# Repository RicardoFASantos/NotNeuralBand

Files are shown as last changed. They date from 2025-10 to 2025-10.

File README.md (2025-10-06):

## 🎥 Vintage Video gallery

### General Pre-trained gestures based on muscle and motion signals
Assembly Tutorial (https://www.youtube.com/watch?v=8NtrBwCGjhw)

### Assembly of a 3D printed bracelet with a PCB board and sensors
Assembly Tutorial (https://www.youtube.com/watch?v=L2T6ioK4wVY)

---

## ✨ Features

- **Analog Front-End:** TI ADS1294 – 4-channel, 24-bit ADC with integrated EMG front-end  
- **MCU:** ATmega1284P – 8-bit AVR, 128KB Flash, 16KB SRAM  
- **Motion Sensing:** NXP MMA8652 3-axis accelerometer  
- **Wireless:** BR-LE4.0-D2A Bluetooth Low Energy module  
- **LED Driver:** IS31FL3199 with RGB LED indicators  
- **Power Management:**
  - MCP73831 Li-Ion/Li-Po charger  
  - TPS78233 LDO regulator  
  - NCP300L voltage detector  

- **Connectivity:**
  - Micro-USB charging & power  
  - 2x pin headers for expansion/debugging  
  - UART/SPI/I²C exposed  

---

## 🔧 Hardware Overview

- **PCB Material:** FR4, 1.6mm, 0.35µm Cu  
- **Board Layers:** 2-layer design  
- **Main Blocks:**
  - Power supply & battery charging  
  - Biosignal AFE (EMG)  
  - Microcontroller control  
  - Bluetooth module  
  - LED indicators  

---

## 🛠️ Manufacturing

To order PCBs:

1. Use the **Gerber files** in `/hardware`.  
2. Upload to a PCB manufacturer (e.g., JLCPCB, PCBWay, OSH Park).  
3. Provide BOM to source components.  
4. Assemble manually or via pick-and-place.

---

## ⚠️ Design Notes

- This design uses a **virtual ground electrode** implementation.  
  No physical ground electrode is required for operation, as the ADS1294 reference (RLD) is internally stabilized.  
  This simplifies assembly and makes the device more wearable.  

---

## 🚀 Getting Started

1. **Assemble the board** following the BOM.  
2. **Program the ATmega1284P** using ISP or bootloader (Arduino-compatible toolchains supported).  
3. **Power via Li-Ion battery or micro-USB**.  
4. **Connect via Bluetooth** to stream biosignals.  

---

## 📜 License

This project is released under the **CERN Open Hardware License v2**.  
You are free to **study, modify, produce, and distribute** this hardware, provided modifications and derivatives remain open.  

See [LICENSE](LICENSE) for details.

---

## 🤝 Contributing

Pull requests are welcome!  
You can help with:
- Firmware development examples  
- Better assembly guides  
- Testing & validation reports  
- Migrating schematics into KiCad for wider community use  

---

## 📧 Contact

Developed originally by **Ricardo Santos** with his friends from college Andreia Dias, Dora Inácio, Eduardo e Rui Santos.
For questions, suggestions, or collaborations:  
- Email: ricardo.santos.eb@gmail.com 
- LinkedIn: [ricardofasantos](https://www.linkedin.com/in/ricardofasantos/)  
- Twitter/X: [@RicardoSan43564](https://twitter.com/RicardoSan43564)
Open-sourced by the community for further research and prototyping.

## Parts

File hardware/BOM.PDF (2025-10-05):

## BOM -Minerva

Designator | Comment | Description | Footprint | Quantity | Value
BT1 | BR-LE4.0-D2A | BR-LE4.0-D2A | WML-C29A | 1
C1, C5, C7, C11, C14, C18, C27, C31 | C0402 | Capacitor | C0402 | 8 | 1nF
C2, C6, C8, C12, C15, C19, C28, C32, C33, C34, C36, C37, C40, C41 | C0402 | Capacitor | C0402 | 14 | 100nF
C3, C9, C16, C21, C24, C26, C29, C35, C38, C39, C42, C44, C46, C48 | C0402 | Capacitor | C0402 | 14 | 1uF
C4, C10, C17, C25, C30, C43, C45 | C0402 | Capacitor | C0402 | 7 | 0.1uF
C13, C23 | C0402 | Capacitor | C0402 | 2 | 0.01uF
C20 | C0603 | Capacitor | C0402 | 1 | 22uF
C22 | C0603 | Capacitor | C0402 | 1 | 10uF
C47, C49 | C0603 | Capacitor | C0603 | 2 | 4.7uF
D1 | LED2 | Typical RED, GREEN, YELLOW, AMBER GaAs LED | 3.2X1.6X1.1 | 1
FID1, FID2, FID3 | FD | Fiducial 1.5mm | Fiducial | 3
IC1 | MCP6041T-E/OT | MCP6041T-E/OT | SOT23-5 | 1
JP1 | 2x3 pinos | Pinos Macho Duplos 2.54mm | IDC-6 | 1
L1 | 5R | | 1206R | 1
P1 | WN09DH | | WN06DH | 1
P2 | 1551629-2 | Micro USB Splashproof | microUSB | 1
P3 | Header 2 | Header, 2-Pin | HDR1X2 | 1
Q2 | TP0101K | MOSFET P-channel 20V, 0.58A, SOT23 | SOT-23 | 1
R1, R23, R25, R26, R27, R30, R31, R32, R33, R40, R41, R42, R43 | R0402 | Resistor | R0402 | 13 | 10k
R2, R3, R4, R5, R6, R7, R8, R9, R11, R12, R13, R14, R18, R19, R20, R21 | R0402 | Resistor | R0402 | 16 | 348k
R10, R16, R17 | R0402 | Resistor | R0402 | 3 | 392k
R15, R22, R24, R38 | R0402 | Resistor | R0402 | 4 | 0
R28, R29 | R0402 | Resistor | R0402 | 2 | 300K
R34 | R0402 | Resistor | R0402 | 1 | 470
R35, R37, R44 | R0402 | Resistor | R0402 | 3 | 100k
R36, R45, R46, R47, R48, R49, R50, R51 | R0402 | Resistor | R0402 | 8 | 1M
R39 | R0402 | Resistor | R0402 | 1 | 330k
RGB1, RGB2, RGB3, RGB4, RGB5, RGB6 | RGB | LX0404SIUPGUSB | LX0404SIUPGUSB | 6
SW1 | | | Push Button | 1
U1 | ADS1294IPAG | 4-Channel, 24-Bit ADC with Integrated ECG Front End, -40 to 85 degC, 64-pin QFP (PAG64), Green (RoHS & no Sb/Br) | TI-PAG64_N | 1
U2 | ATmega1284P-MUR | 8-bit AVR Microcontroller, 128KB Flash, 4KB EEPROM, 16KB SRAM, 44-pin VQFN, Industrial Grade (-40°C to 85°C), Reel | 44M1_N | 1
U3 | MMA8652FCR1 | Accelerometer 3-Axis, 2g/4g/8g, 12 bit, DFN-10 (MMA8652FCR1) | MMA8652FC | 1
U4 | IS31FL3199 | | VQFN-20 (3x3mm) | 1
U5 | TPS78233 | Voltage regulator LDO, 150mA, IQ 0,5uA, SOT23-5 (TPS78233DDC) | SOT23-5 | 1

U6 | MCP73831T-2ACI/OT | Miniature Single-Cell, Fully Integrated Li-Ion, Li-Polymer Charge Management Controller, 4.2V, 5-Pin SOT-23, Industrial Temperature, Tape and Reel | SOT23-5 | 1
U7 | NCP300L | Voltage detector 3.4V, SOT23-5 NCP300L | SOT23-5 | 1
Y1 | Resonator | AVX | Resonator | 1

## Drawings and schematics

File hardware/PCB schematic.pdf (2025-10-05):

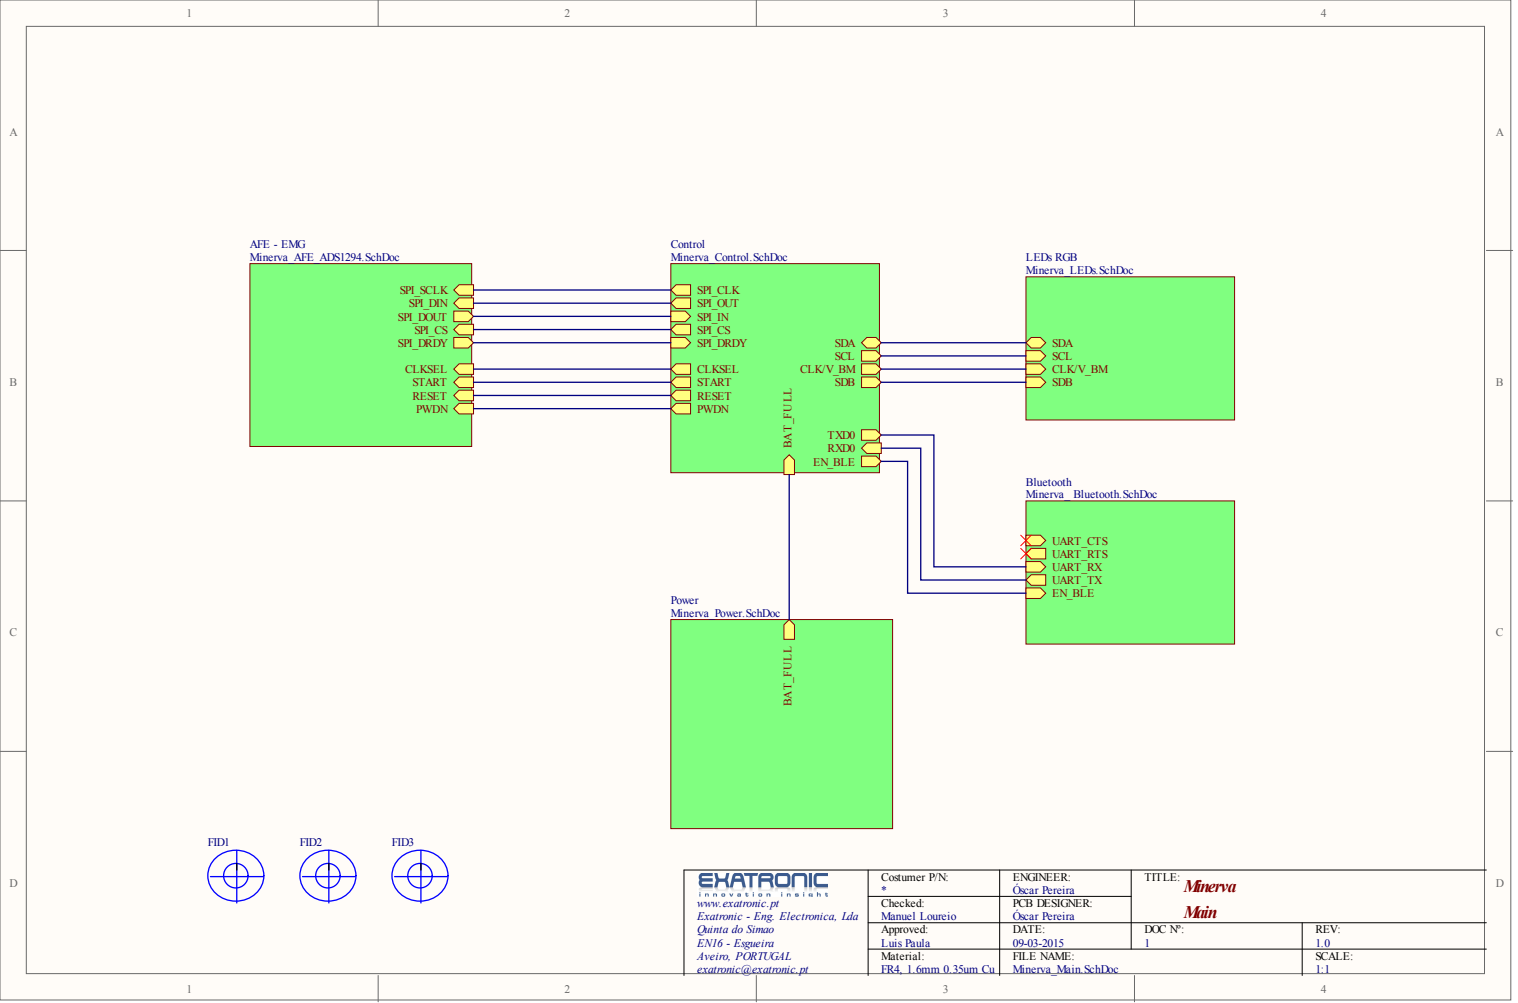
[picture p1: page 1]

www.exatronic.pt
Exatronic - Eng. Electronica, Lda
Quinta do Simao
EN16 - Esgueira
Aveiro, PORTUGAL
exatronic@exatronic.pt

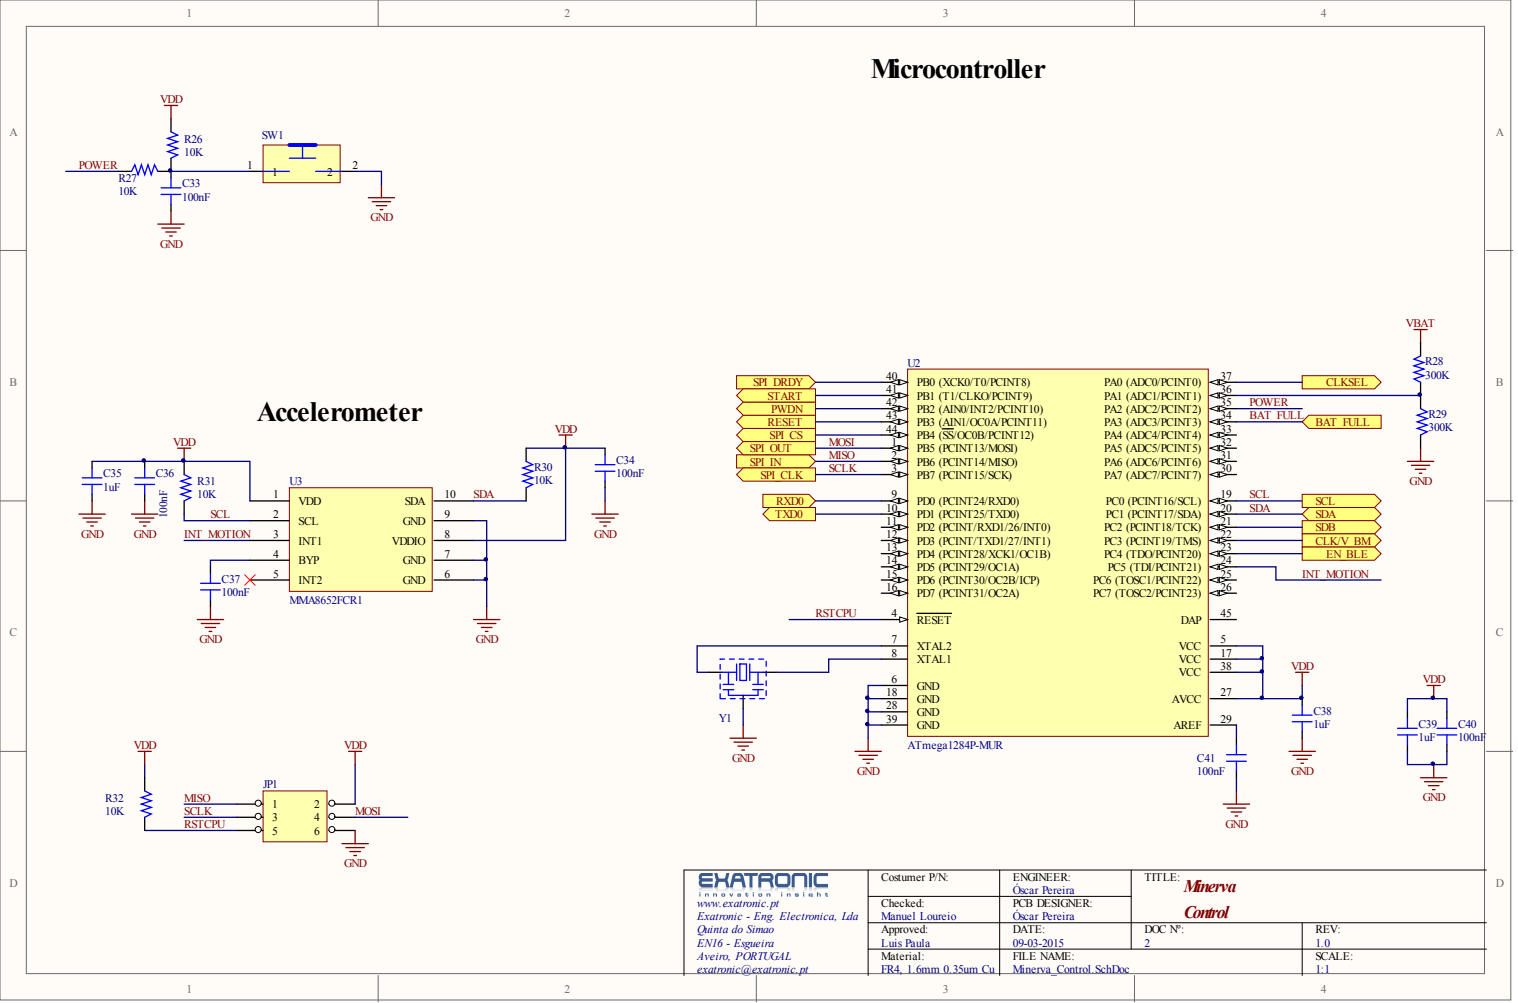
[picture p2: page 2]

XTAL1 8

GND 18

GND 39

www.exatronic.pt
Exatronic - Eng. Electronica, Lda

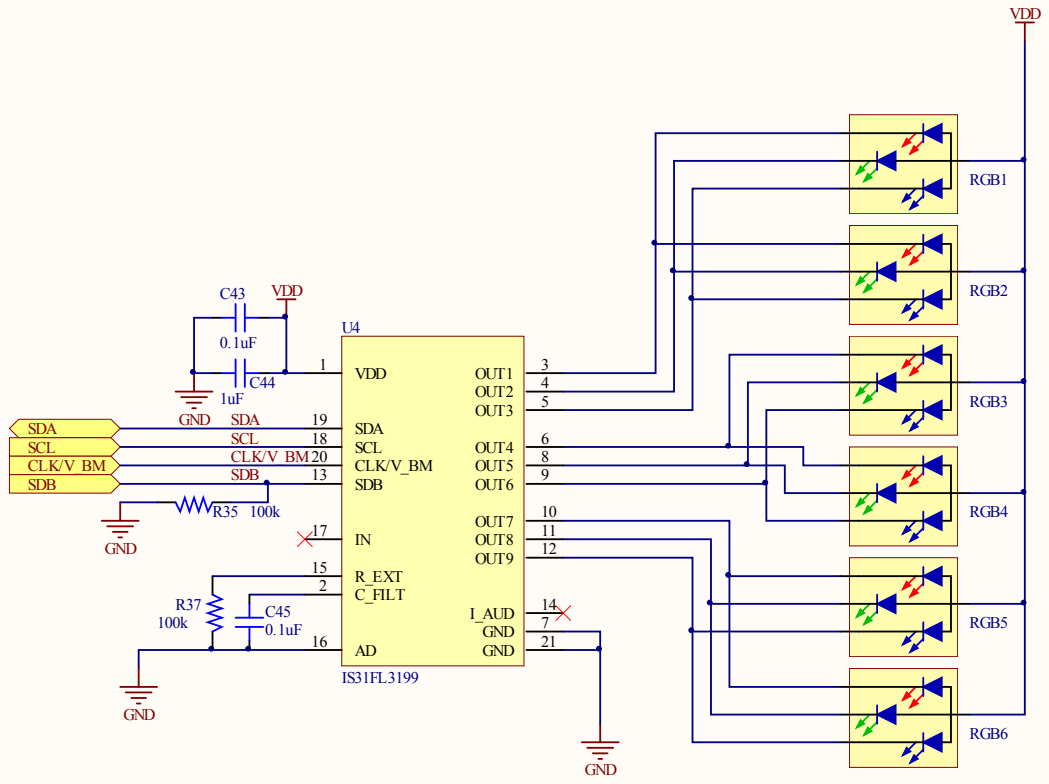
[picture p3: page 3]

1 0
1 1
1 2

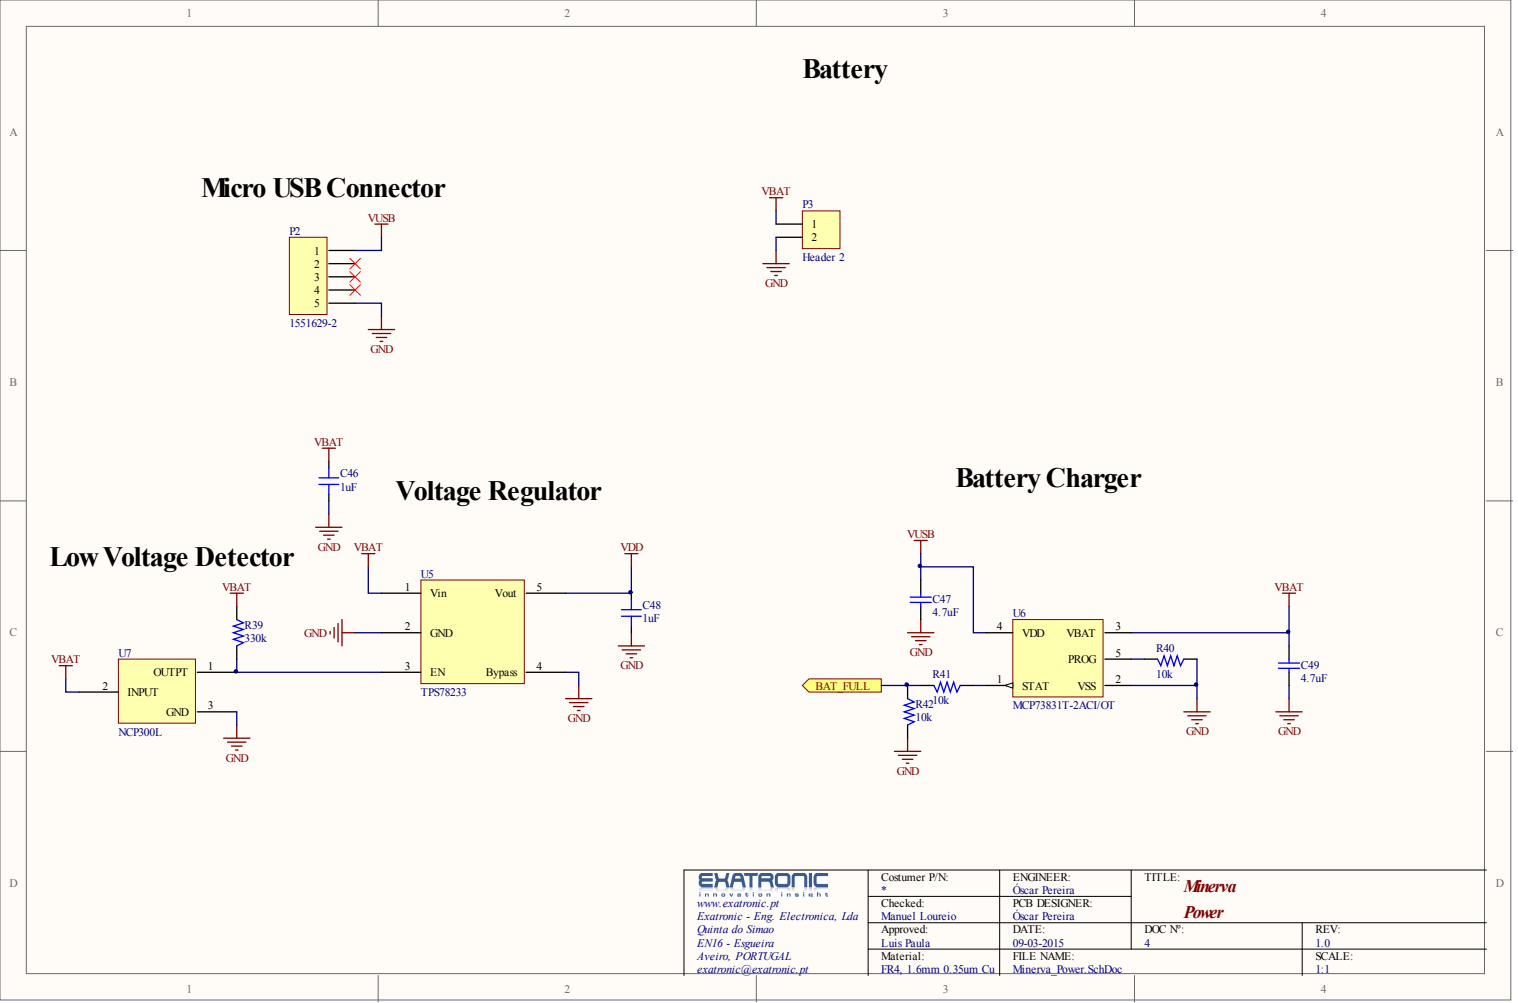
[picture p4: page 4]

Micro USB Connector VUSB

Battery Charger Voltage Regulator

www.exatronic.pt
Exatronic - Eng. Electronica, Lda

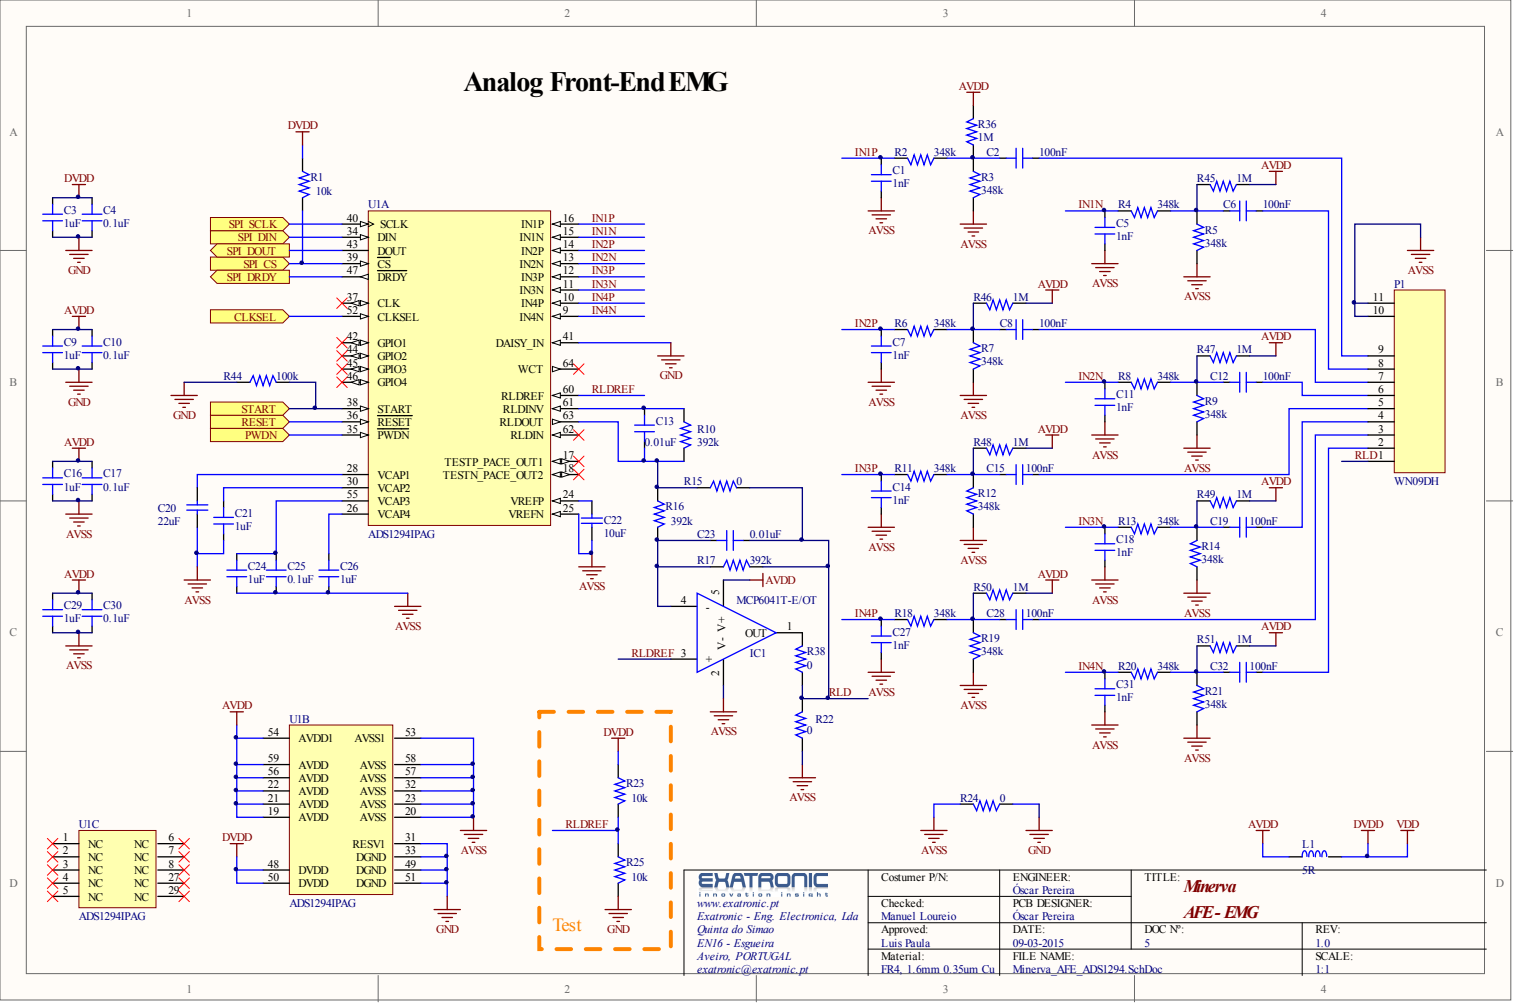
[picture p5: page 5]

4 3 | 1 4 IN2 P AVS R4
3 9 | 1 3 IN2 N

R4 7 1 M | AVDD

5 9 | 5 8
5 6 | 5 7
2 2 | 3 2
2 1 | 2 3
1 9 | 2 0

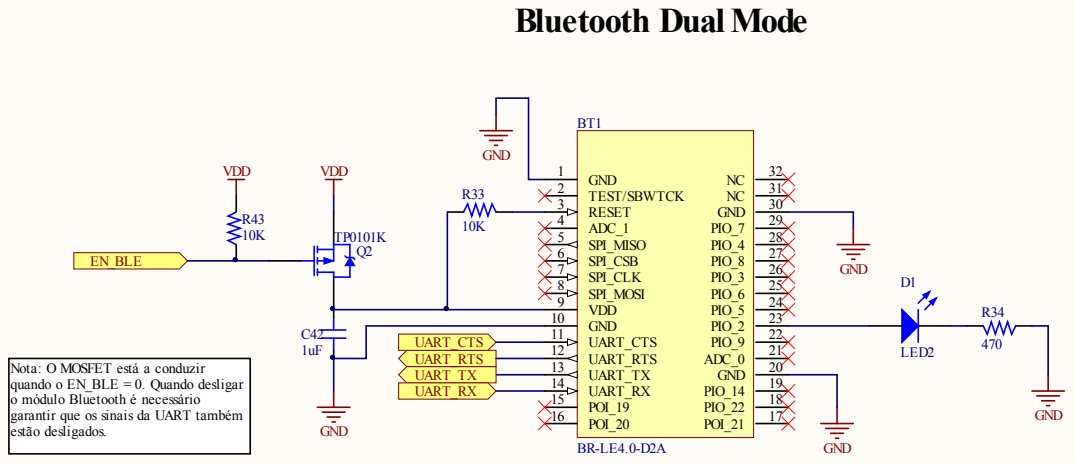
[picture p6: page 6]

UART _ C T S UART _RT S UART _T X | 1 1

1 4 | 1 9
1 5 | 1 8
